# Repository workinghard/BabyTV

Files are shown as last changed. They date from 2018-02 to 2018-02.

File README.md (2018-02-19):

# BabyTV
BabyTV running on Atmega328p and using WS2812B display

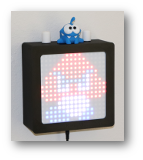
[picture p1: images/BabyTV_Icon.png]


## Index
 1. [Overview](#overview)
 2. [Hardware](#hardware)
 3. [Software](#software)
 4. [3D Parts](#3dparts)
 5. [Full Partlist](#partlist)

## Overview
Display a nice looking pixel grafic on a 16x16 matrix. Both static images and animations are possible and implemented. Let your child switch between images/animations with a remote. Control brightness and switch between "channels" with two knobs.  

You can [watch a demo on youtube](https://youtu.be/bw_D5chaiGM)

This project is inspired by others which are using Neopixel matrix and developed already stable and fast working frameworks for arduino. 

## Hardware
A 16x16 neopixel matrix with a WS2812B controller is being used as a display. It is driven by an arduino nano board with a atmega328p chip. One rotary encoder knob allows to switch between "channels" back and forth. One potentiometer is being used for brightness control. The infrared sensor is picking up any signals and switching a channel based on it.





[Full schematics can be found in the project](https://github.com/workinghard/BabyTV/raw/master/Schematics/BabyTV.pdf)

## Software
FastLed framework was picked for fast animations. Each channel (Image/Animation) is in a separate c-file. A rotary encoder framework is based on a software scan. A hardware interrupt for RE was not being used to guarantee flawless communication with the display. No additional dependencies are required. Full source code can be found in the Arduino folder.  
 
## 3Dparts
All needed 3D parts can be found in the STL folder or on [Thingiverse](https://www.thingiverse.com/thing:2790910). Using PLA filament there should be no dimensional issues. If you are using ABS or any material which shrinks, you will most likely need to scale the parts up.

I printed body and Back with PLA and everything else with ABS on my [Original Prusa i3 MK2S](https://shop.prusa3d.com/en/) 

----

## Partlist
 * 3D printer with at least 200x200mm build plate [like Original Prusa i3 MK3](https://shop.prusa3d.com/en/)
 * 16x16 pixel board with WS2812B chipset [like this on Amazon](https://www.amazon.com/gp/product/B01DC0IOCK)
 * Arduino nano with atmega328p chipset [like this on Aliexpress](https://www.aliexpress.com/item/Nano-CH340-ATmega328P-MicroUSB-Compatible-for-Arduino-Nano-V3-0/32740641316.html)
 * Rotary Encoder [like this on Aliexpress](https://www.aliexpress.com/item/Free-Shipping-10pcs-lot-Rotary-encoder-switch-five-feet-short-handle-Best-quality/32543561073.html)
 * 5V/10A Power supply [like this on Amazon](https://www.amazon.com/ALITOVE-Transformer-Converter-5-5x2-1mm-100V-240V/dp/B01M0KLECZ)
 * 2x 100nF Capacitor
 * 4x 10k Ohm Resistor
 * Any linear potentiometer
 * Any infrared receiver

[logo]: https://github.com/workinghard/BabyTV/raw/master/images/BabyTV_Icon.png "Logo"
[demo]: http://img.youtube.com/vi/bw_D5chaiGM/0.jpg "Demo"
[ElectronicsOverview]: https://github.com/workinghard/BabyTV/raw/master/images/BabyTV_Electronics_Overview.JPG
[ElectronicsMainboard]: https://github.com/workinghard/BabyTV/raw/master/images/BabyTV_Electronics_Mainboard.JPG

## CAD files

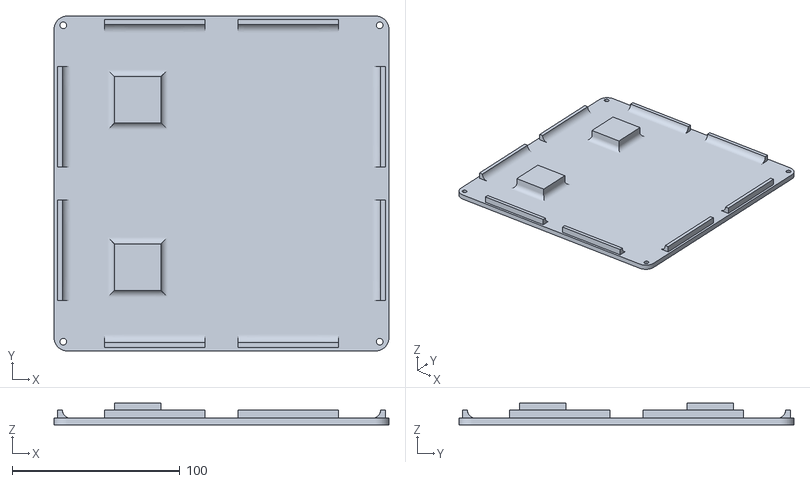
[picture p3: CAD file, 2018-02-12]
STL/Back.stl
200.0 x 200.0 x 13.0

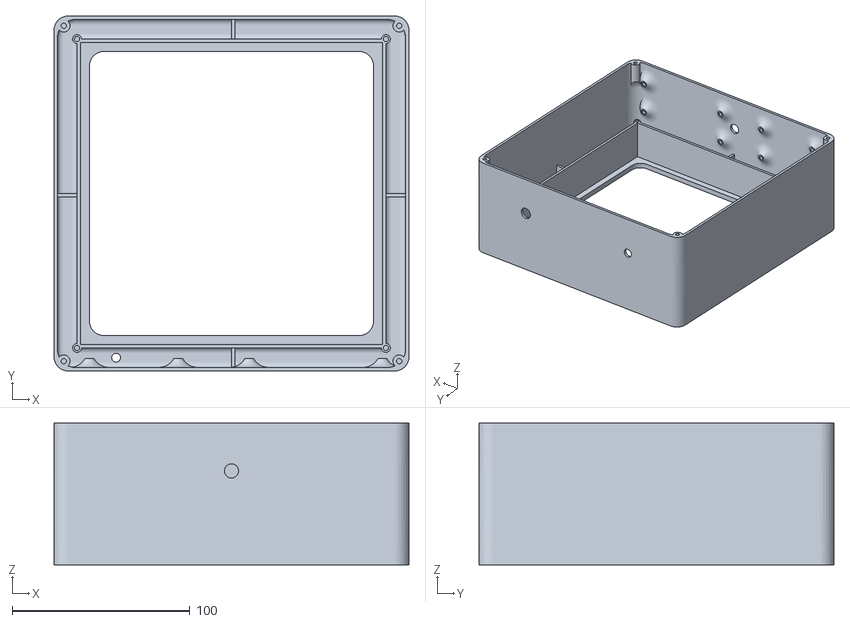
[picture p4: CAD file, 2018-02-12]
STL/Body.stl
200.0 x 200.0 x 80.0

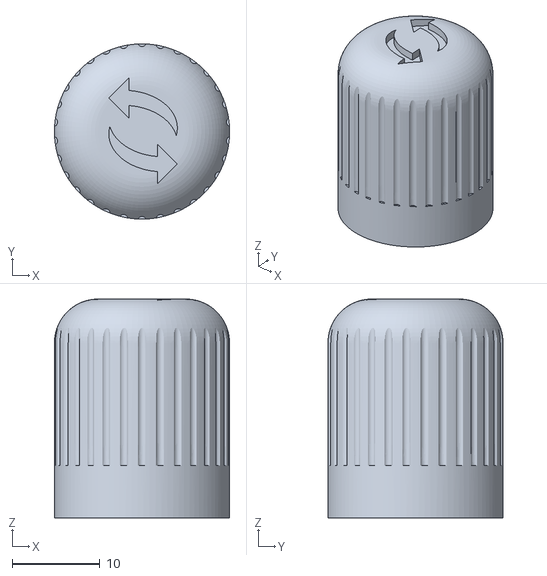
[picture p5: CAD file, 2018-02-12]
STL/KnobSwitch.stl
20.0 x 20.0 x 25.0

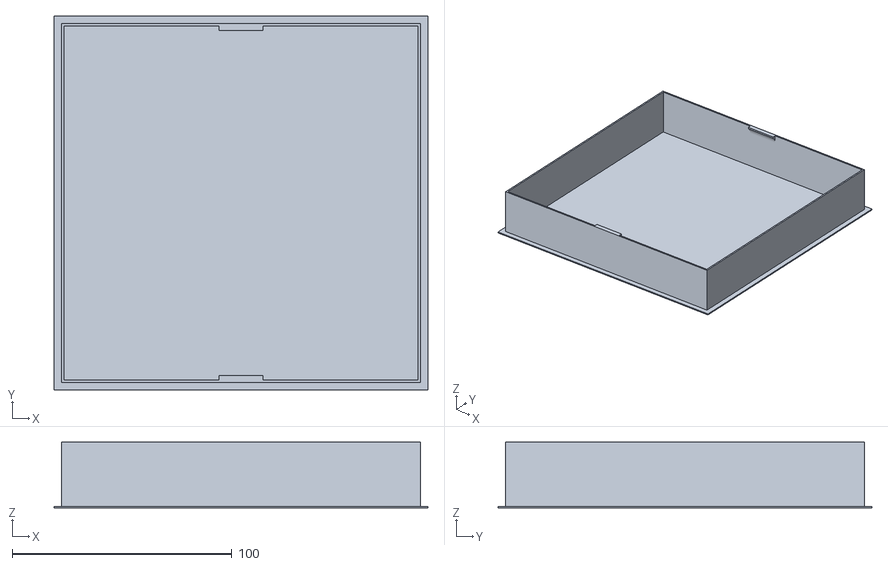
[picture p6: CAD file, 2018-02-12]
STL/Screen-Front.stl
170.0 x 170.0 x 30.0

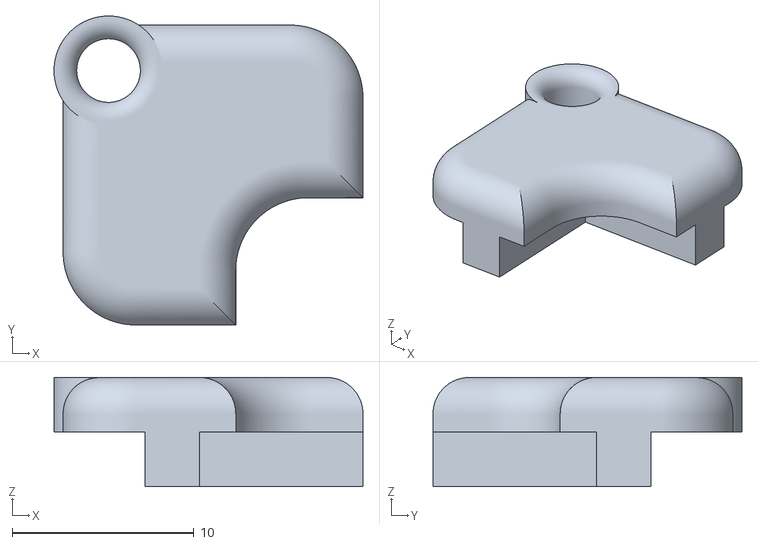
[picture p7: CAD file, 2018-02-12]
STL/ScreenHolder.stl
17.0 x 17.0 x 6.00

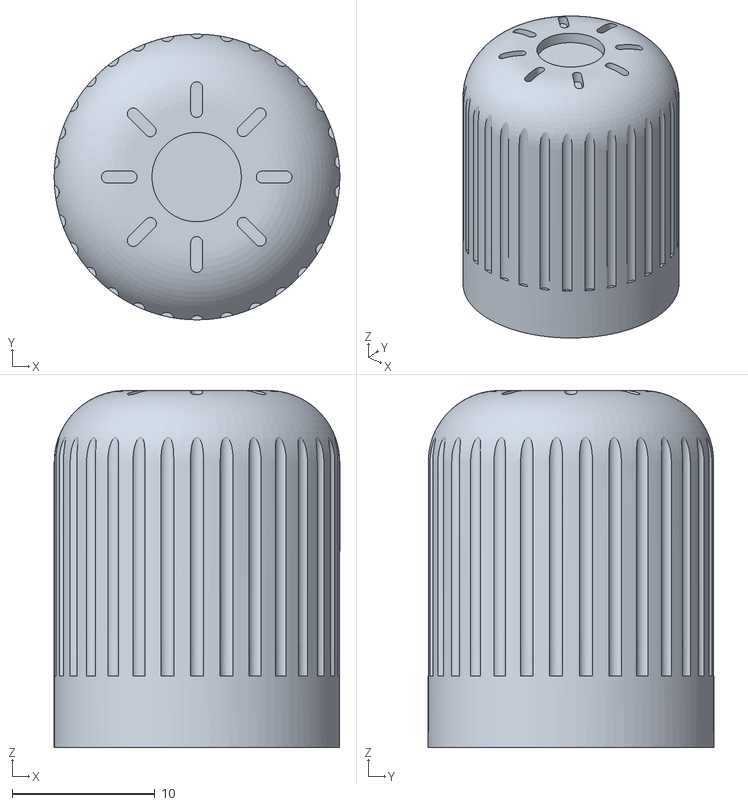
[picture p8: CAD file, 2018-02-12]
STL/KnobBrightness.stl
20.0 x 20.0 x 25.0

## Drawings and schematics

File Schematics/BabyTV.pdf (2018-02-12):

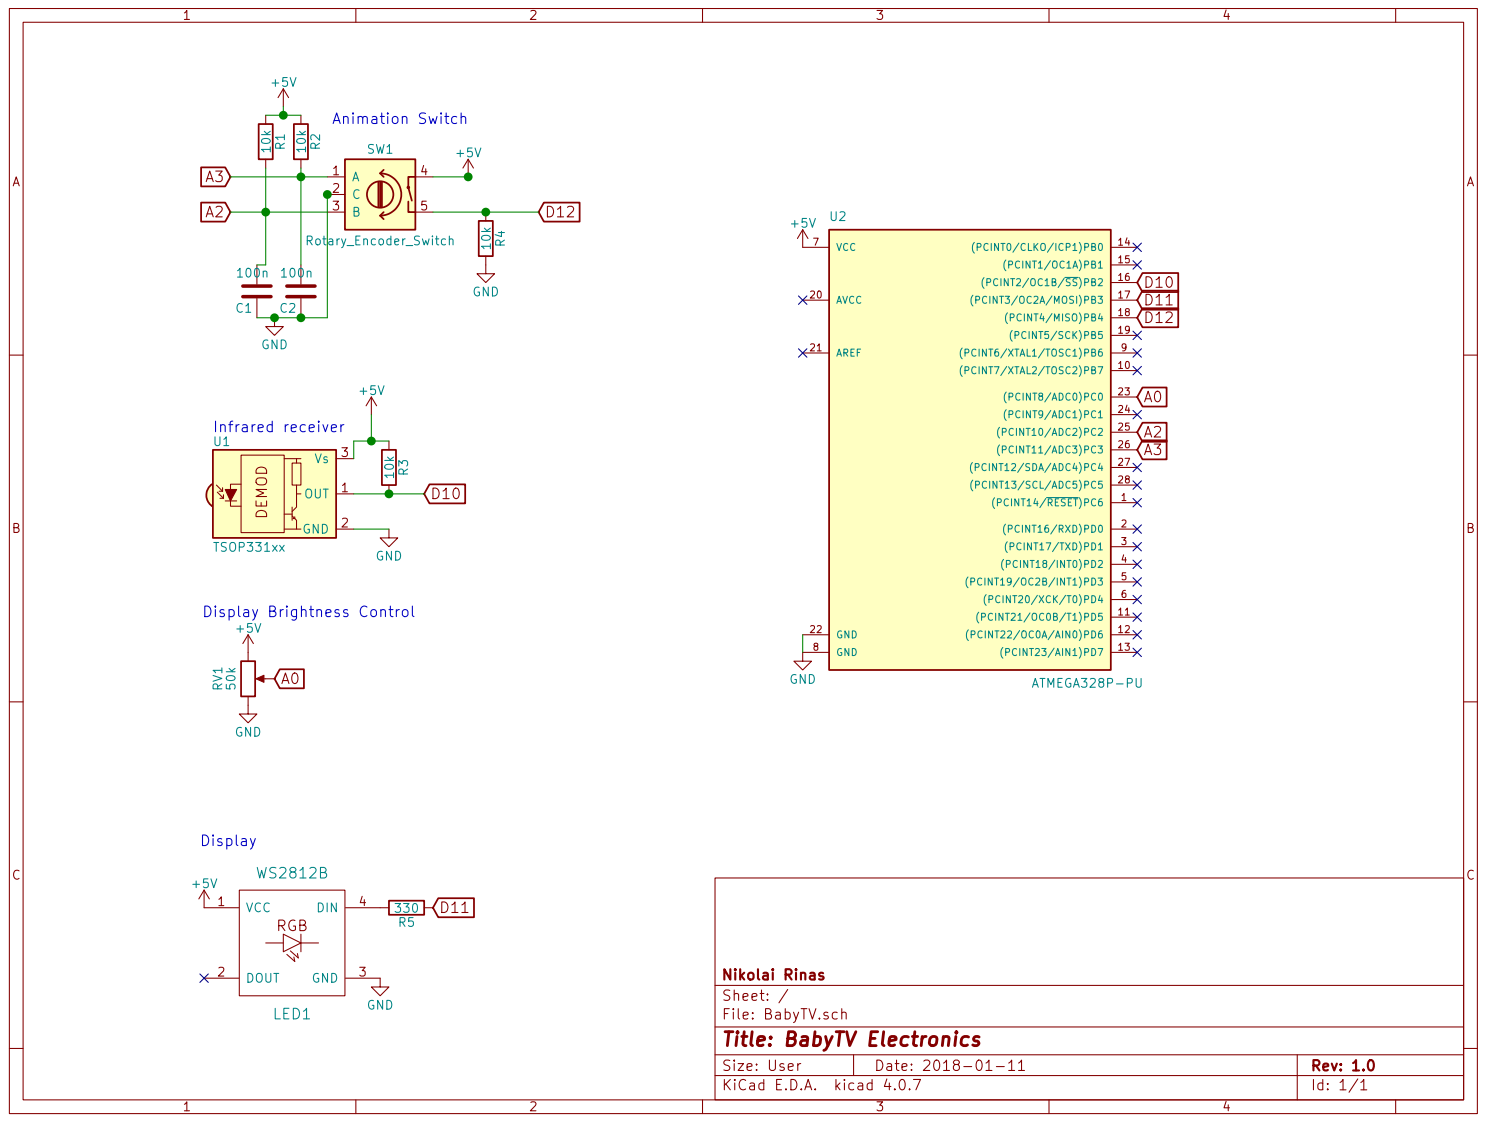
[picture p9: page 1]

File: BabyTV.sch Sheet: / Nikolai Rinas

Id: 1/1 Title: BabyTV Electronics

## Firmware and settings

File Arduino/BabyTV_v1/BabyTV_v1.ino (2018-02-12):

//
//  BabyTV
//
//  Created by Nikolai Rinas on 01/11/2018.
//  Copyright (c) 2018 Nikolai Rinas. All rights reserved.
//
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
// http://howtomechatronics.com/tutorials/arduino/rotary-encoder-works-use-arduino/
// https://www.arduino.cc/en/tutorial/potentiometer
// http://www.instructables.com/id/How-to-use-Potentiometer-Arduino-Tutorial/

// http://www.digole.com/tools/PicturetoC_Hex_converter.php
// Code format: DEC
// Display position: X0/Y0
// Used for: 262K Color(3bytes/pixel:XXXXXXXX00)

#include "FastLED.h"
#include <RotaryEncoder.h>

FASTLED_USING_NAMESPACE

#define WAITFORTICKS 5000

#define DATA_PIN    11
#define LED_TYPE    WS2812B
#define COLOR_ORDER GRB
#define NUM_LEDS    256
CRGB leds[NUM_LEDS];

#define BUTTON_PIN 12
int buttonReading = 0;           // the current value read from the input pin
int buttonCurrent_state = LOW;    // the debounced input value
long buttonTime = 0;         // the last time the output pin was sampled
int buttonCounter = 0;       // how many times we have seen new value
int buttonDebounce_count = 10; // number of millis/samples to consider before declaring a debounced input
int buttonState = 1;       // 0 = display off , 1 = display on , default on
 
int currBrightness = 50;
//#define BRIGHTNESS         50  // Inital brightness default value, will be changed later
#define FRAMES_PER_SECOND  120

#define ARRAY_SIZE(A) (sizeof(A) / sizeof((A)[0]))

const uint8_t kMatrixWidth  = 16;
const uint8_t kMatrixHeight = 16;
const uint8_t kMatrixSerpentineLayout = true;

void matrix_code();
void rainbowWithGlitter();
void confetti();

// Mario animation
#include "imgMario1.c" // Mario1
const byte *gMarioFrames[3] = { mario1, mario2, mario3 };
void showMario1();
// Mushroom animation
#include "imgMushroom1.c" // Mushroom1
const byte *gMushroomFrames[3] = { mushroom1, mushroom2 };
void showMushroom1();
// Bee animation
#include "imgBee1.c"  // Bee1
const byte *gBeeFrames[3] = { bee1, bee2 };
void showBee1();
// Bat animation
#include "imgBat1.c"  // Bee1
const byte *gBatFrames[3] = { bat1, bat2 };
void showBat1();
// Frog animation
#include "imgFrog1.c"  // Bee1
const byte *gFrogFrames[3] = { frog1, frog2, frog3 };
void showFrog1();

// List of patterns to cycle through.  Each is defined as a separate function below.
typedef void (*SimplePatternList[])();
SimplePatternList gPatterns = { showMario1, showMushroom1, showBee1, showBat1, showFrog1, matrix_code, rainbowWithGlitter, confetti };

uint8_t gCurrentPatternNumber = 0; // Index number of which pattern is current
uint8_t gHue = 0; // rotating "base color" used by many of the patterns

int tmpIndexI = 0;
int tmpIndexJ = 0;

#define POTPIN A0
int potValue=0; //save analog value

// Setup a RoraryEncoder for pins A2 and A3:
RotaryEncoder encoder(A2, A3);

int gCurrentFrameNumber = 0;

#include <IRremote.h>

int RECV_PIN = 10;

IRrecv irrecv(RECV_PIN);
decode_results results;

void setup() {
  delay(3000); // 3 second delay for recovery
  
  // tell FastLED about the LED strip configuration
  FastLED.addLeds<LED_TYPE,DATA_PIN,COLOR_ORDER>(leds, NUM_LEDS).setCorrection(TypicalLEDStrip);

  // set master brightness control
  FastLED.setBrightness(currBrightness);

  Serial.begin (9600);
  irrecv.enableIRIn(); // Start the receiver

  pinMode(POTPIN, INPUT);
  pinMode(BUTTON_PIN, INPUT);
}

void loop() {

  checkRotary();

  checkButton();

  EVERY_N_MILLISECONDS( 100 ) { // 100 ms for stable reading
    if ( buttonState > 0 ) { // only if display is on
      checkBrightness();
    }
  }  

  EVERY_N_MILLISECONDS( 100 ) {
   if (irrecv.decode(&results)) {
     if ( results.value != 4294967295 ) {
       //Serial.println(results.value, HEX);
       nextPattern();
     }
     irrecv.resume(); // Receive the next value
    }
  }
  
  // Call the current pattern function once, updating the 'leds' array
  gPatterns[gCurrentPatternNumber]();

  FastLED.show();
    // insert a delay to keep the framerate modest
  FastLED.delay(1000/FRAMES_PER_SECOND);

  // do some periodic updates
  EVERY_N_MILLISECONDS( 20 ) { gHue++; } // slowly cycle the "base color" through the rainbow
}

void checkButton() {
  if(millis() != buttonTime) {
    buttonReading = digitalRead(BUTTON_PIN);

    if( buttonReading == buttonCurrent_state && buttonCounter > 0) {
      buttonCounter--;
    }
    if(buttonReading != buttonCurrent_state) {
       buttonCounter++; 
    }
    // If the Input has shown the same value for long enough let's switch it
    if(buttonCounter >= buttonDebounce_count) {
      buttonCounter = 0;
      buttonCurrent_state = buttonReading;
      if ( buttonCurrent_state == HIGH ) {
        // button pressed
        if ( buttonState == 1 ) { // Display is on, let's turn it off
          buttonState = 0;
          currBrightness = 0;
        }else{  // Display is off, let's turn it on
          buttonState = 1;
        }
      }else{
        // button released
      }
    }
    buttonTime = millis();
  }
}

void checkBrightness() {
  int diff = 0;
  potValue = analogRead(POTPIN);
  potValue = map(potValue, 0, 1023, 0, 150); // Map the value to the brightness
  if ( potValue > currBrightness ) {
    diff = potValue - currBrightness;
  }else{
    diff = currBrightness - potValue;
  }
  if ( diff > 2 ) { // Change Brightness in 2er steps
    FastLED.setBrightness(potValue);
    currBrightness = potValue;
  }
}

void nextFrame(int count) {
  // add one to the current pattern number, and wrap around at the end
  gCurrentFrameNumber = (gCurrentFrameNumber + 1) % count;
}

void nextPattern() {
  // add one to the current pattern number, and wrap around at the end
  gCurrentPatternNumber = (gCurrentPatternNumber + 1) % ARRAY_SIZE( gPatterns);
  gCurrentFrameNumber = 0; // reset the frame counter
  //Serial.println("Next pattern");
}
void lastPattern() {
  // add one to the current pattern number, and wrap around at the end
  gCurrentPatternNumber = (gCurrentPatternNumber - 1) % ARRAY_SIZE( gPatterns);
  gCurrentFrameNumber = 0; // reset the frame counter
  //Serial.println("Last pattern");
}

void checkRotary() {
  for (tmpIndexI=0;tmpIndexI<WAITFORTICKS;tmpIndexI++) {
    static int pos = 0;
    encoder.tick();
  
    int newPos = encoder.getPosition();
    if (pos != newPos) {
      //Serial.print(newPos);
      //Serial.println();
      if ( newPos > pos ) {
        nextPattern();
      }else{
        lastPattern();
      }
      pos = newPos;
    } // if
  }
}

// convert bitmap to x/y coordinates
uint16_t getImgX(uint16_t index) {
  return index % kMatrixWidth;
}
uint16_t getImgY(uint16_t index) {
  return (kMatrixWidth - (index / kMatrixWidth) - 1);
}

// convert x/y cordinates to LED index on zig-zag grid
uint16_t getIndex(uint16_t x, uint16_t y) {
  uint16_t index;
  if (y == 0) {
    index = x;
  } else if (y % 2 == 0) {
    index = y * kMatrixWidth + x;
  } else {
    index = ((y * kMatrixWidth) + (kMatrixWidth-1)) - x;
  }
  return index;
}

// Confetti (OK)
void confetti()  {
  // random colored speckles that blink in and fade smoothly
  fadeToBlackBy( leds, NUM_LEDS, 10);
  int pos = random16(NUM_LEDS);
  leds[pos] += CHSV( gHue + random8(64), 200, 255);
}

// Rainbow with Glitter (OK)
void rainbow() {
  // FastLED's built-in rainbow generator
  fill_rainbow( leds, NUM_LEDS, gHue, 7);
}
void addGlitter( fract8 chanceOfGlitter) {
  if( random8() < chanceOfGlitter) {
    leds[ random16(NUM_LEDS) ] += CRGB::White;
  }
}
void rainbowWithGlitter() {
  // built-in FastLED rainbow, plus some random sparkly glitter
  rainbow();
  addGlitter(80);
}

// Matrix code (OK)
void matrix_code() { 
  EVERY_N_MILLIS(100) // falling speed
  {
    // move code downward
    // start with lowest row to allow proper overlapping on each column
    for (int8_t row=0; row<kMatrixWidth; row++) {
      for (int8_t col=0; col<kMatrixHeight; col++) {
        if (leds[getIndex(row, col)] == CRGB(0,255,25)) {
          leds[getIndex(row, col)] = CRGB(27,130,29); // create trail
          if (col > 0) {
            leds[getIndex(row, col-1)] = CRGB(0,255,25);
          }
        }
      }
    }

    // fade all leds
    for(tmpIndexI = 0; tmpIndexI < NUM_LEDS; tmpIndexI++) {
      if (leds[tmpIndexI].g != 255) leds[tmpIndexI].nscale8(192); // only fade trail
    }

    // check for empty screen to ensure code spawn
    bool emptyScreen = true;
    for(tmpIndexI=0; tmpIndexI < NUM_LEDS; tmpIndexI++) {
      if (leds[tmpIndexI]) {
        emptyScreen = false;
        break;
      }
    }

    // spawn new falling code
    if (random8(3) == 0 || emptyScreen) { // lower number == more frequent spawns 
      int8_t spawnX = random8(kMatrixWidth);
      leds[getIndex(spawnX, kMatrixHeight-1)] = CRGB(0,255,25 );
    }

    //FastLED.show();
  }
}

void showMario1() {
  tmpIndexJ = 0;
  EVERY_N_MILLISECONDS( 200 ) {  // 200ms frame change
    for (tmpIndexI=0;tmpIndexI<768;tmpIndexI=tmpIndexI+3) {
      leds[getIndex(getImgX(tmpIndexJ),getImgY(tmpIndexJ))].r = pgm_read_byte_near(gMarioFrames[gCurrentFrameNumber] + tmpIndexI);
      leds[getIndex(getImgX(tmpIndexJ),getImgY(tmpIndexJ))].g = pgm_read_byte_near(gMarioFrames[gCurrentFrameNumber] + tmpIndexI+1);
      leds[getIndex(getImgX(tmpIndexJ),getImgY(tmpIndexJ))].b = pgm_read_byte_near(gMarioFrames[gCurrentFrameNumber] + tmpIndexI+2);      
      tmpIndexJ=tmpIndexJ+1;
    }
    nextFrame(3);
  }
}


void showMushroom1() {
  tmpIndexJ = 0;
  EVERY_N_MILLISECONDS( 200 ) {  // 200ms frame change
    for (tmpIndexI=0;tmpIndexI<768;tmpIndexI=tmpIndexI+3) {
      leds[getIndex(getImgX(tmpIndexJ),getImgY(tmpIndexJ))].r = pgm_read_byte_near(gMushroomFrames[gCurrentFrameNumber] + tmpIndexI);
      leds[getIndex(getImgX(tmpIndexJ),getImgY(tmpIndexJ))].g = pgm_read_byte_near(gMushroomFrames[gCurrentFrameNumber] + tmpIndexI+1);
      leds[getIndex(getImgX(tmpIndexJ),getImgY(tmpIndexJ))].b = pgm_read_byte_near(gMushroomFrames[gCurrentFrameNumber] + tmpIndexI+2);      
      tmpIndexJ=tmpIndexJ+1;
    }
    nextFrame(2);
  }
}

void showBee1() {
  tmpIndexJ = 0;
  EVERY_N_MILLISECONDS( 200 ) {  // 200ms frame change
    for (tmpIndexI=0;tmpIndexI<768;tmpIndexI=tmpIndexI+3) {
      leds[getIndex(getImgX(tmpIndexJ),getImgY(tmpIndexJ))].r = pgm_read_byte_near(gBeeFrames[gCurrentFrameNumber] + tmpIndexI);
      leds[getIndex(getImgX(tmpIndexJ),getImgY(tmpIndexJ))].g = pgm_read_byte_near(gBeeFrames[gCurrentFrameNumber] + tmpIndexI+1);
      leds[getIndex(getImgX(tmpIndexJ),getImgY(tmpIndexJ))].b = pgm_read_byte_near(gBeeFrames[gCurrentFrameNumber] + tmpIndexI+2);      
      tmpIndexJ=tmpIndexJ+1;
    }
    nextFrame(2);
  }
}

void showBat1() {
  tmpIndexJ = 0;
  EVERY_N_MILLISECONDS( 200 ) {  // 200ms frame change
    for (tmpIndexI=0;tmpIndexI<768;tmpIndexI=tmpIndexI+3) {
      leds[getIndex(getImgX(tmpIndexJ),getImgY(tmpIndexJ))].r = pgm_read_byte_near(gBatFrames[gCurrentFrameNumber] + tmpIndexI);
      leds[getIndex(getImgX(tmpIndexJ),getImgY(tmpIndexJ))].g = pgm_read_byte_near(gBatFrames[gCurrentFrameNumber] + tmpIndexI+1);
      leds[getIndex(getImgX(tmpIndexJ),getImgY(tmpIndexJ))].b = pgm_read_byte_near(gBatFrames[gCurrentFrameNumber] + tmpIndexI+2);      
      tmpIndexJ=tmpIndexJ+1;
    }
    nextFrame(2);
  }
}

void showFrog1() {
  tmpIndexJ = 0;
  EVERY_N_MILLISECONDS( 200 ) {  // 200ms frame change
    for (tmpIndexI=0;tmpIndexI<768;tmpIndexI=tmpIndexI+3) {
      leds[getIndex(getImgX(tmpIndexJ),getImgY(tmpIndexJ))].r = pgm_read_byte_near(gFrogFrames[gCurrentFrameNumber] + tmpIndexI);
      leds[getIndex(getImgX(tmpIndexJ),getImgY(tmpIndexJ))].g = pgm_read_byte_near(gFrogFrames[gCurrentFrameNumber] + tmpIndexI+1);
      leds[getIndex(getImgX(tmpIndexJ),getImgY(tmpIndexJ))].b = pgm_read_byte_near(gFrogFrames[gCurrentFrameNumber] + tmpIndexI+2);      
      tmpIndexJ=tmpIndexJ+1;
    }
    nextFrame(3);
  }
}

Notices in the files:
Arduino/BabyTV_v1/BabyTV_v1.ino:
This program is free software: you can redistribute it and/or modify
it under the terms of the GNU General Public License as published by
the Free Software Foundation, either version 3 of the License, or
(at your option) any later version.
